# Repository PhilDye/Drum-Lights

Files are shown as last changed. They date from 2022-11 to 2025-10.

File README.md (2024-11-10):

# Drum Lights

## About

This project provides synchronised, colour-changing, remote-control LED lights for a drum band (but could be used for other similar applications). It was first created for [Swan Samba](https://www.swansamba.co.uk) to use for evening/winter performances.

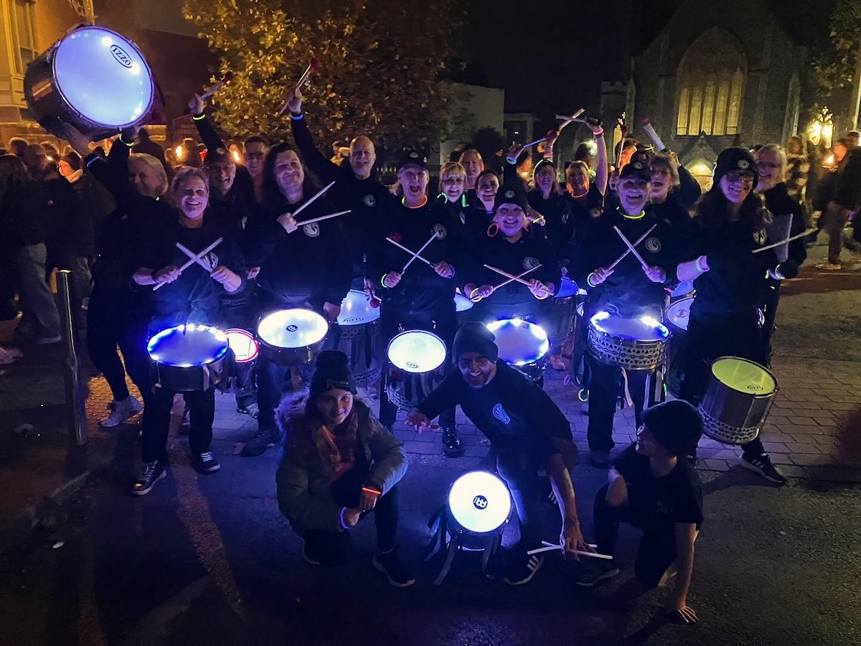
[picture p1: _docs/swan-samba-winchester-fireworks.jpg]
Swan Samba at Winchester Fireworks


Hundreds of hours have gone into developing this project - if you make use of it and wish to thank me, then please consider a donation;



Contributions to improve this documentation or code would also be very welcome to help other users.

## Skills & Requirements

This is a technically complex project! Whilst I've partly documented it here, to use it successfully you'll need to improvise a bit and will need some experience with;

- sourcing and assembling the electronic components (eg from AliExpress), including soldering techniques

- building and uploading the firmware using [Visual Studio Code](https://code.visualstudio.com/) and [PlatformIO](https://platformio.org/)

- 3D-printing for the enclosure boxes

If you are not confident with these skills, then this probably isn't the project for you; I'm happy to answer the odd question, but this project is provided 'as-is' and as a hobby I'm unable to provide extensive support, sorry!

## Overview

The system consists of two components;

- Transmitter (TX) - provides a web-based interface to select required colours/patterns, and broadcasts a radio signal to the receivers.

- Receiver (RX) - receives the broadcast radio signal and drives a strip of individually-addressable LED pixels mounted inside the shell of each drum.

Both are powered by portable USB battery packs ('power banks'), typically carried in a pocket by each band member (or could be mounted to each drum).

## Transmitter

The transmitter (TX) consists of an ESP32 dev-kit board plus a RF24-based radio module, mounted on proto-board.

Although the RF24 modules use the 2.4Ghz ISM radio band, they are not WiFi (which is available on the ESP32 already); this was chosen for low-latency and avoiding the need for a network router for a large number of receivers (which would not be able to connect simultaneously to the ESP32 hotspot).

Significantly better results have been found with the E01-2G4M27D module, rather than the cheaper basic nRF24L01-PA-LNA which suffers RF interference and instability.

The ESP32 also broadcasts a WiFi personal hotspot (configured as a captive portal) to allow a user who wants to control the display to connect simply from their mobile phone.

It runs an AsyncWebServer serving a simple HTML/CSS/JS page from a filesystem, with control commands received by websocket (allowing simultaneous control from multiple clients if required).

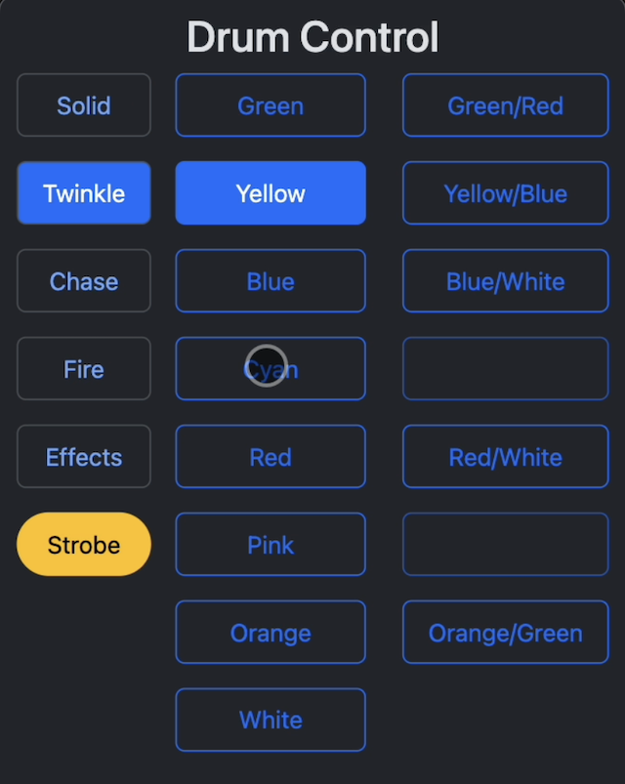
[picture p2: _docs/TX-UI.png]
TX UI


The RF24 module uses a configurable transmit power with multiple channels available, but does not avoid packet collision with other sources using the same frequency. For this reason we retransmit each command multiple times in quick succession, in the hope that 'one gets through'. It also requires a stable 3.3v supply, which at high-power transmission could exceed that available from the ESP32, so a separate buck converter is used fed from the power supply.

## Receiver

The receiver (RX) consists of an ESP8266-based Wemos D1-mini clone board, plus a RF24 module, mounted on a PCB.

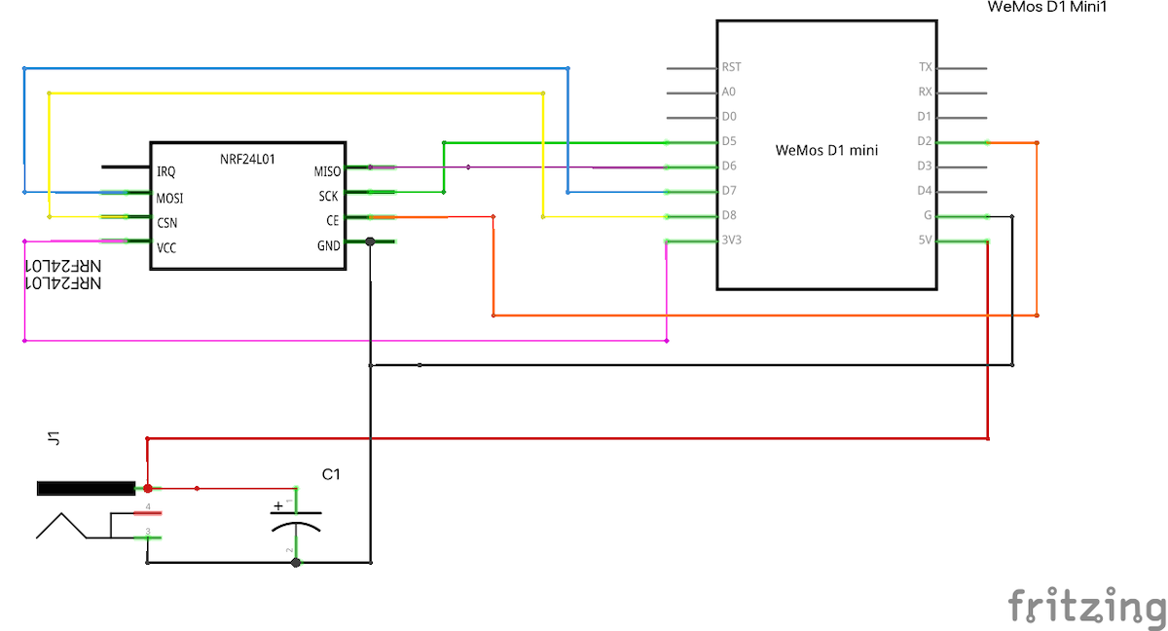
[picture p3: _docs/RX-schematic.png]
RX schematic


Better reliability has been found with the E01-ML01DP4 module, rather than the cheaper basic nRF24L01. 

It receives radio commands from the TX and uses these to drive a strip of WS2812B LEDs ("neopixels") using the excellent [FastLED](https://fastled.io) library.

Best-practice often requires the use of a 3.3v level-shifter and/or resistor in the data line, but testing showed this not to be neccessary, probably given the short data-line length, although a capacitor _is_ provided on the power supply (although as a DC source, USB battery packs are probably sufficiently stable already). 

The receiver reads a configuration file with the number of LEDs available in the attached strip, and uses this to dynamically compute moving effects to suit the varying drum sizes within a band. This file should be uploaded to the filesystem on each board.

## LED mounting

Self-adhesive IP65 WS2812B LED strip is mounted inside the shell of each drum, approx a quarter of the way from the top, around the full circumference. 

The strip requires 3-core cable: 5V, data and ground;
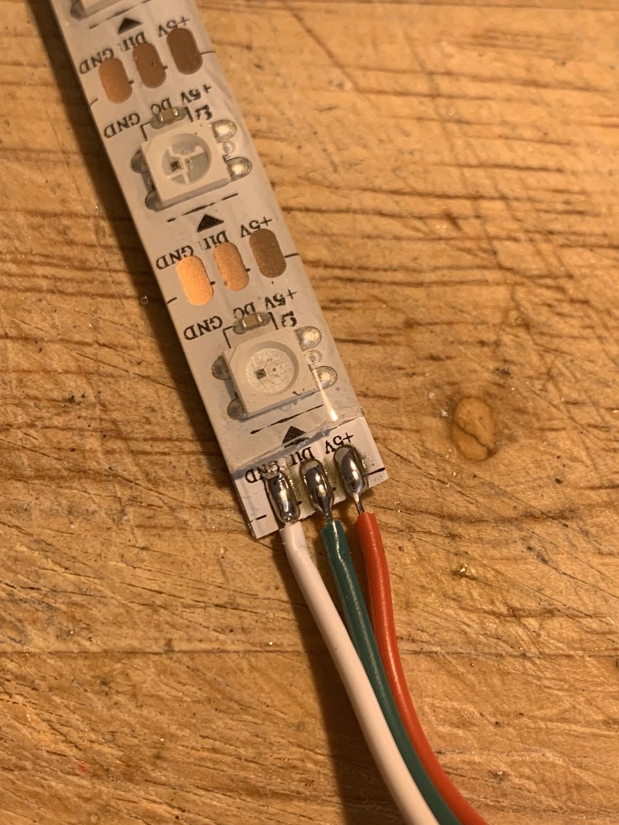
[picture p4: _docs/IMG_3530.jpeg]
WS2812B strip with wires attached


Ensure this is sealed with silicone or hot-glue to prevent water ingress, and insulated with heatshrink;
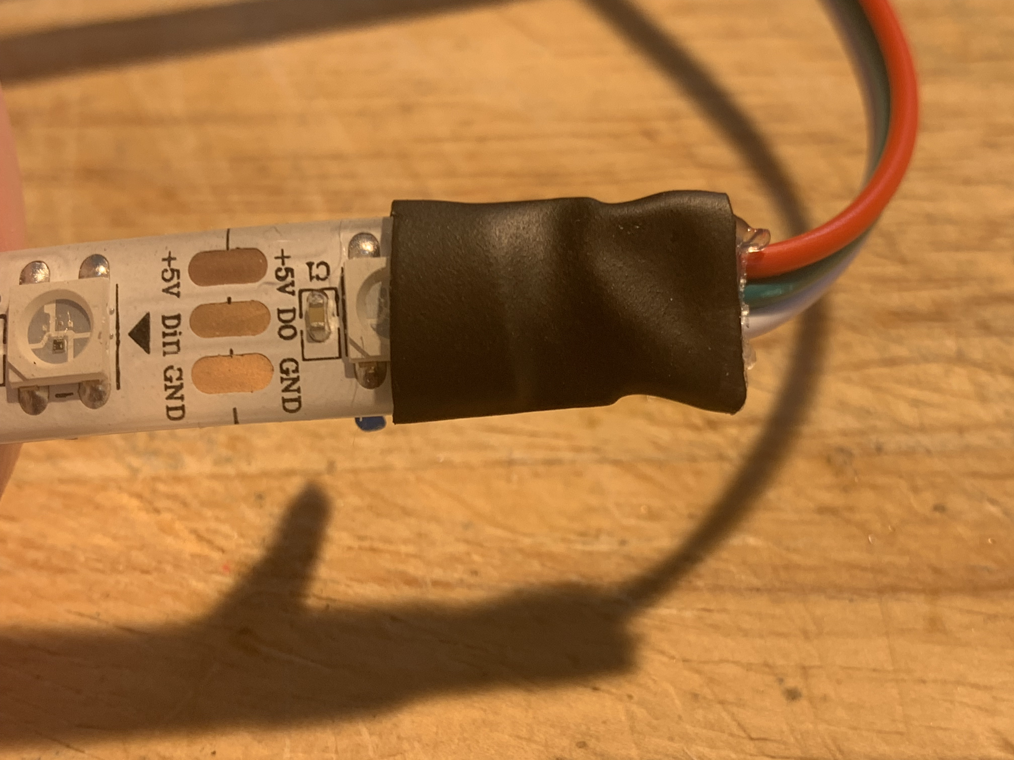
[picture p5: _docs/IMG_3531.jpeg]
WS2812B strip with heatshrink


The cable exits through the sound hole/port and runs to an enclosure holding the RX board.

## Enclosures

Both RX and TX are mounted in custom 3D-printed boxes; the RX in particular is designed to secure the components against vibration. Power is supplied via a 5.5mm DC jack using a [USB cable](https://www.kenable.co.uk/en/usb-cables-adapters/usb-20-cables/usb-20-adapters/7629-usb-to-dc-power-cable-usb-20-for-21mm-x-55mm-5v-2a-2000ma-1m-007629-5055383476299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).

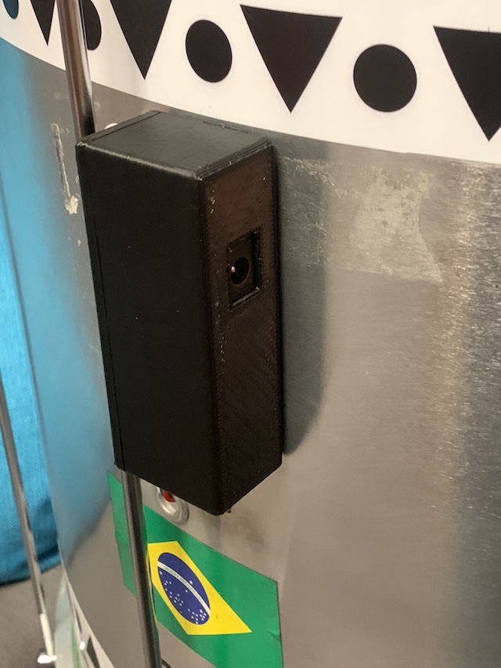
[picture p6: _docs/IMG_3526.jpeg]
3D-printed enclosure mounted on a surdo drum


Experience has shown it's best to mount the RX on the *rear* of all drums with 3M VHB double-sided tape. Ensure the TX is positioned at the rear of the band too, to avoid metal-shelled drums blocking the RF signal. _Ensure players know this to mount their drum accordingly!_

## PCBs

After breadboard prototyping, initial builds were built on protoboard but for more than a small handful of boards (which require plenty of soldering!), it's advisable to consider custom-printed PCBs. 

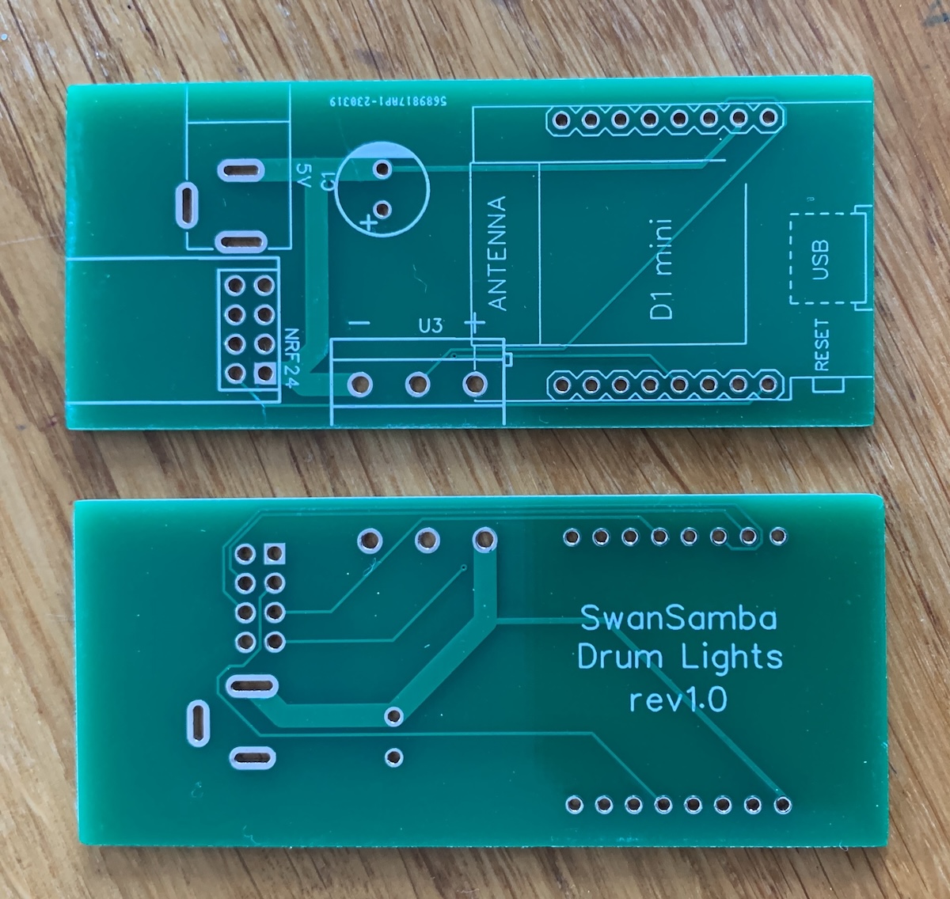
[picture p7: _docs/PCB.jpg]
Custom PCB


[Design files are provided](PCB/) for [KiCAD](https://www.kicad.org/) with Gerber output files ready for use at [JLCPCB](https://jlcpcb.com/).

## Effects

The lighting patterns currently available are;

- Static: every pixel the same colour, available in various colours.
- Chase: 4 quadrants of moving pixels with a fading 'tail', rotating around the drum, available in various colours.
- Twinkle: a number of pixels randomly light then fade, available in various colours.
- Fire: a 'flickering' flame effect in varying colours.
- 'Rio Spin': 3 segments of solid colour (blue/green/yellow) rotating around the drum.
- 'Rio Disco': twinkle, with blue/green/yellow only.
- 'Rio Flag': a blue/green/yellow sequence representing the Brazilian flag, rotating around the drum.
- Rainbow: a classic FastLED multi-colour effect, rotating around the drum.
- Hazards: 2 segments of orange at the side of each drum, designed to imitate a vehicle's hazard lights when stopped.
- Strobe: rapid, short-duration flashes of full-intensity white - perfect for big hits!
- 999: alternate high-frequency flashing blue strobes (named after the UK emergency-services telephone number).
- Auto: randomises most of the above every 30s; ideal to 'fire-and-forget' if no-one is available to run the show.

Many of the FastLED demo effects suit 1D (strip) or 2D (panel) setups; the circular/ring configuration here does present some additional challenges, but further effects are really only limited by imagination (although compexity of the control UI should be considered).

## Synchronicity

Currently, all drums receive the same command and hence display the same colour/pattern at the same time. The speed of the rotating patterns (ie RPM) is not synchronised across varying diameter drums; early experiments showed this to be hard to maintain a smooth frame rate at slower speeds (on smaller drums); temporal dithering may help this.

It would be relatively simple to use addressing or channel features of the RF24 to control each drum type seperately, allowing complex displays and patterns 'across' the band. The main obstacle is likely to be the complexity of the control UI.

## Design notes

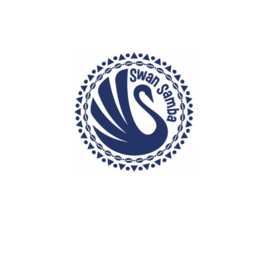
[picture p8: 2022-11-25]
TX/app/src/public/mstile-150x150.png

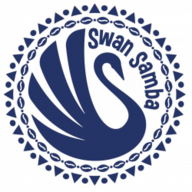
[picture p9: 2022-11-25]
TX/app/src/public/android-chrome-192x192.png

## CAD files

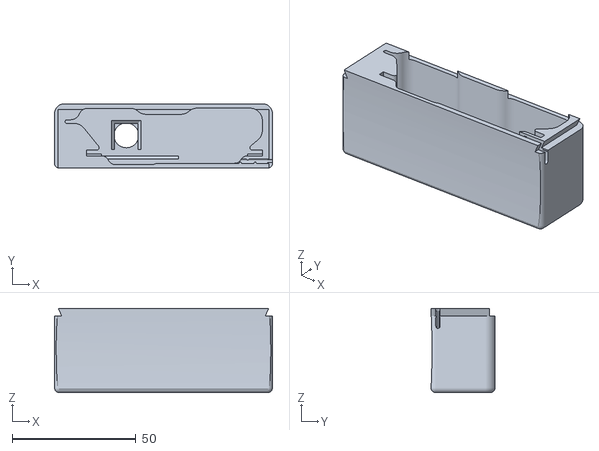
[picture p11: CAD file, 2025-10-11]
STL/box.stl
88.0 x 26.0 x 34.0

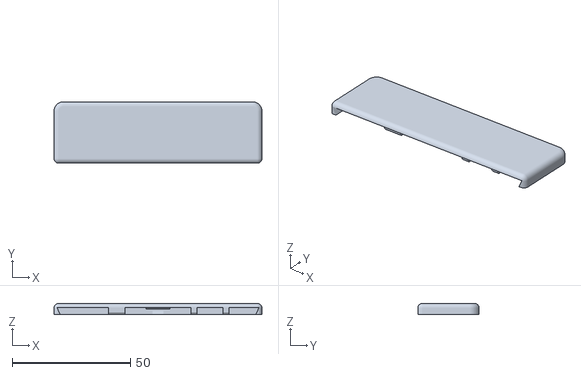
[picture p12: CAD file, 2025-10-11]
STL/lid.stl
88.0 x 26.0 x 4.75

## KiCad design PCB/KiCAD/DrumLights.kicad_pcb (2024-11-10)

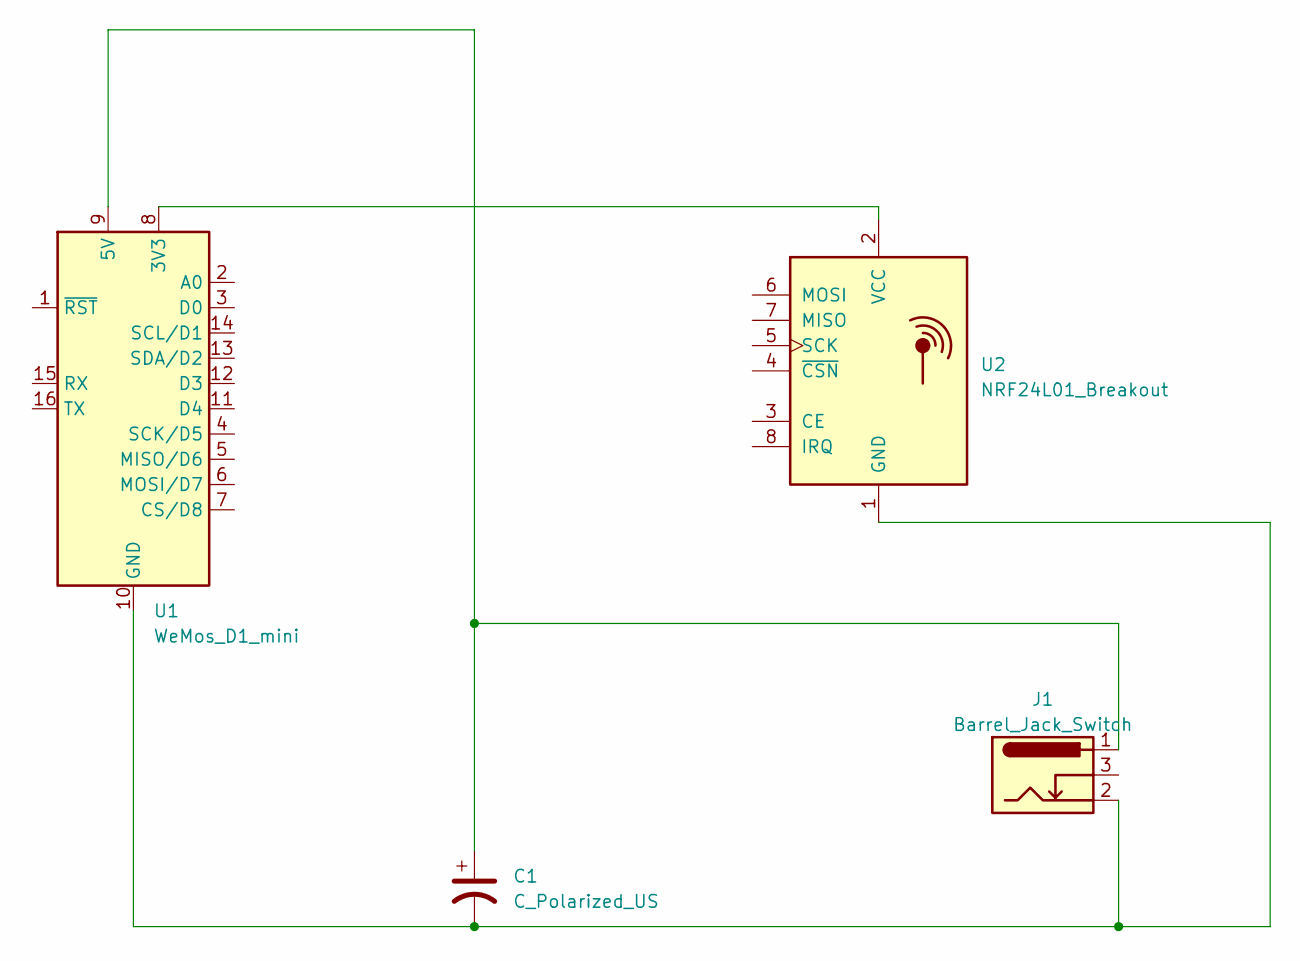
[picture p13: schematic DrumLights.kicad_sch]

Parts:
C1: C_Polarized_US; CP_Radial_D6.3mm_P2.50mm
J1: Barrel_Jack_Switch; BarrelJack_Horizontal
U1: WeMos_D1_mini; WEMOS_D1_mini_light
U2: NRF24L01_Breakout; nRF24L01_Breakout

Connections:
unnamed: U1.8 (3V3), U2.2 (VCC)
unnamed: C1.1, J1.1, U1.9 (5V)
unnamed: C1.2, J1.2, U1.10 (GND), U2.1 (GND)

Board: 2 copper layers, 4 parts (0 on the bottom side), 3 nets, no tracks yet.

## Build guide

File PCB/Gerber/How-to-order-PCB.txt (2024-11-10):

How to Order PCB

Please refer to:
https://docs.easyeda.com/en/PCB/Order-PCB

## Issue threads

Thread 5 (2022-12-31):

Continual re-broadcasting current mode

PhilDye, 2022-12-31:
To allow for drums rebooting (eg from power issues or joining late), need to periodically re-transmit the current mode. Need to consider power usage, and not 'restarting' any current animation (eg jumping the rotation position)

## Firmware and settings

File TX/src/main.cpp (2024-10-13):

/* Drum Lights transmitter
 *
 * by Phil Dye <phil@phildye.org>
 * for Swan Samba Band <https://www.swansamba.co.uk>
 *
 * Works with the Drum Lights Receiver
 * to send desired colour/pattern commands from a web UI
 * by nRF24L01 radio module
 *
 */

#include <WiFi.h>
#include <AsyncTCP.h>
#include <ESPAsyncWebServer.h>
#include <DNSServer.h>
#include <esp_wifi.h> //Used for mpdu_rx_disable android workaround
#include <SPI.h>
#include <nRF24L01.h>
#include <RF24.h>
#include <LittleFS.h>
#include <ArduinoJson.h>
#include <millisDelay.h>

#include <secrets.h>

// Setup the network
const byte DNS_PORT = 53;
const byte HTTP_PORT = 80;
const IPAddress localIP(192, 168, 4, 1);          // the IP address the web server, Samsung requires the IP to be in public space
const IPAddress gatewayIP(192, 168, 4, 1);        // IP address of the network should be the same as the local IP for captive portals
const IPAddress subnetMask(255, 255, 255, 0); // no need to change: https://avinetworks.com/glossary/subnet-mask/
const String localIPURL = "http://192.168.4.1";   // a string version of the local IP with http, used for redirecting clients to your webpage
#define DNS_INTERVAL 30

// Setup the servers
AsyncWebServer webServer(HTTP_PORT);
AsyncWebSocket ws("/ws");
DNSServer dnsServer;

// Setup the nRF24L01 radio
#define NRF24L01_PIN_CE 17
#define NRF24L01_PIN_CS 5
RF24 radio(NRF24L01_PIN_CE, NRF24L01_PIN_CS);
const byte address[5] = {'R', 'x', 'A', 'A', '1'};
const byte RETRANSMITS = 5; // how many times we retransmit every message, for reliability in noisy RF environments

#define LED_BUILTIN 2

int CurrentMode = 0;

const unsigned long AUTO_TIME = 30000; // in mS
const int AUTO_MODE = -1;
millisDelay autoDelay; // the delay object

const int autoModes[24] = {
    1, 2, 3, 4, 5, 6, 7, 8,
    11, 12, 13, 14, 15, 16, 17, 18,
    81, 82, 83, 84, 85, 86, 87, 88};

class CaptiveRequestHandler : public AsyncWebHandler
{
public:
    explicit CaptiveRequestHandler(String redirectTargetURL) :
        targetURL("http://" + WiFi.softAPIP().toString() + redirectTargetURL)
    {
    }
    virtual ~CaptiveRequestHandler() {}

    const String targetURL;

    bool canHandle(AsyncWebServerRequest *request) override
    {
        // redirect if not in wifi client mode (through filter)
        // and request for different host (due to DNS * response)
        if (request->host() != WiFi.softAPIP().toString())
            return true;
        else
            return false;
    }

    void handleRequest(AsyncWebServerRequest *request) override
    {
        request->redirect(targetURL);
        log_d("Captive handler triggered. Requested %s%s -> redirecting to %s", request->host().c_str(), request->url().c_str(), targetURL.c_str());
    }
};

void initRadio()
{
  // initialize the transceiver on the SPI bus
  if (!radio.begin())
  {
    Serial.println(F("Radio hardware is not responding!!"));
    // hold in infinite loop
    while (1)
      digitalWrite(LED_BUILTIN, millis() % 1000 < 500 ? HIGH : LOW);
  }

  radio.openWritingPipe(address);
  // Set the PA Level to try preventing power supply related problems
  radio.setPALevel(RF24_PA_MAX); // RF24_PA_MAX is default
  radio.setAutoAck(false);
  radio.stopListening(); // put radio in TX mode

  radio.printPrettyDetails(); // (larger) function that prints human readable data
}

void setUpWebserver(AsyncWebServer &webServer, const IPAddress &localIP)
{
  	// Required
	webServer.on("/connecttest.txt", [](AsyncWebServerRequest *request) { request->redirect("http://logout.net"); });	// windows 11 captive portal workaround
	webServer.on("/wpad.dat", [](AsyncWebServerRequest *request) { request->send(404); });								// Honestly don't understand what this is but a 404 stops win 10 keep calling this repeatedly and panicking the esp32 :)

	// Background responses: Probably not all are Required, but some are. Others might speed things up?
	// A Tier (commonly used by modern systems)
	webServer.on("/generate_204", [](AsyncWebServerRequest *request) { request->redirect(localIPURL); });		   // android captive portal redirect
	webServer.on("/redirect", [](AsyncWebServerRequest *request) { request->redirect(localIPURL); });			   // microsoft redirect
	webServer.on("/hotspot-detect.html", [](AsyncWebServerRequest *request) { request->redirect(localIPURL); });  // apple call home
	webServer.on("/canonical.html", [](AsyncWebServerRequest *request) { request->redirect(localIPURL); });	   // firefox captive portal call home
	webServer.on("/success.txt", [](AsyncWebServerRequest *request) { request->send(200); });					   // firefox captive portal call home
	webServer.on("/ncsi.txt", [](AsyncWebServerRequest *request) { request->redirect(localIPURL); });			   // windows call home
  
  webServer.addHandler(new CaptiveRequestHandler("/")).setFilter(ON_AP_FILTER); // only when requested from AP
  webServer.serveStatic("/", LittleFS, "/").setDefaultFile("index.html").setCacheControl("max-age=600");;
  webServer.onNotFound([](AsyncWebServerRequest *request) { request->redirect(localIPURL); });

  webServer.begin();
}

void notifyClients()
{
  const size_t size = JSON_OBJECT_SIZE(1);
  StaticJsonDocument<size> json;
  json["mode"] = CurrentMode;

  char msg[32];
  size_t len = serializeJson(json, msg);
  ws.textAll(msg, len);

  Serial.printf("CurrentMode #%d broadcasted to WS\n", CurrentMode);
}

void broadcastRF()
{
  for (size_t i = 0; i < RETRANSMITS; i++)
  {
    radio.write(&CurrentMode, sizeof(CurrentMode), true);
    delay(10);
  }
  Serial.printf("CurrentMode #%d broadcasted to RF\n", CurrentMode);
}

void handleWSMessage(void *arg, uint8_t *data, size_t len)
{
  AwsFrameInfo *info = (AwsFrameInfo *)arg;
  if (info->final && info->index == 0 && info->len == len && info->opcode == WS_TEXT)
  {

    const size_t size = JSON_OBJECT_SIZE(1);
    StaticJsonDocument<size> json;
    DeserializationError err = deserializeJson(json, data);
    if (err)
    {
      Serial.print(F("deserializeJson() failed with code "));
      Serial.println(err.c_str());
      return;
    }

    int previousMode = CurrentMode;

    int newMode = json["mode"];

    Serial.printf("Received mode #%d\n", newMode);

    if (newMode == AUTO_MODE)
    { // auto
      Serial.printf("AUTO mode set ON\n");

      // set a random mode
      newMode = autoModes[random(24)];
      Serial.printf("CurrentMode randomised to #%d\n", newMode);
      autoDelay.start(AUTO_TIME);
    }
    else if (CurrentMode = AUTO_MODE)
    {
      autoDelay.stop();
      Serial.printf("AUTO mode set OFF\n");
    }

    CurrentMode = newMode;
    Serial.printf("CurrentMode set to #%d\n", CurrentMode);

    broadcastRF();

    if (newMode == 98)
    { // revert mode for strobe (RX automatically revert so no need to TX)
      CurrentMode = previousMode;
      Serial.printf("CurrentMode reverted to #%d\n", previousMode);
    }

    notifyClients();
  }
}

void onWSEvent(AsyncWebSocket *server,
             AsyncWebSocketClient *client,
             AwsEventType type,
             void *arg,
             uint8_t *data,
             size_t len)
{

  switch (type)
  {
  case WS_EVT_CONNECT:
    Serial.printf("WebSocket client #%u connected from %s\n", client->id(), client->remoteIP().toString().c_str());
    break;
  case WS_EVT_DISCONNECT:
    Serial.printf("WebSocket client #%u disconnected\n", client->id());
    break;
  case WS_EVT_DATA:
    Serial.printf("WebSocket data received\n");
    handleWSMessage(arg, data, len);
    break;
  case WS_EVT_PONG:
  case WS_EVT_ERROR:
    break;
  }
}

void initWebSocket()
{
  ws.onEvent(onWSEvent);
  webServer.addHandler(&ws);
}

void setUpDNSServer(DNSServer &dnsServer, const IPAddress &localIP)
{
  // Respond to all DNS requests with the ESP's IP
  dnsServer.setErrorReplyCode(DNSReplyCode::NoError);
  dnsServer.setTTL(3600);
  dnsServer.start(DNS_PORT, "*", WiFi.softAPIP());
  Serial.println("DNS server started");
}

void startAccessPoint(const char *ssid, const char *password, const IPAddress &localIP, const IPAddress &gatewayIP, const IPAddress &subnetMask)
{
#define WIFI_CHANNEL 6

  // Set the WiFi mode to access point and station
  WiFi.mode(WIFI_MODE_AP);

  // Configure the soft access point with a specific IP and subnet mask
  WiFi.softAPConfig(localIP, gatewayIP, subnetMask);

  // Start the soft access point with the given ssid, password, channel, max number of clients
  WiFi.softAP(ssid, password, WIFI_CHANNEL);

  // Disable AMPDU RX on the ESP32 WiFi to fix a bug on Android
  esp_wifi_stop();
  esp_wifi_deinit();
  wifi_init_config_t my_config = WIFI_INIT_CONFIG_DEFAULT();
  my_config.ampdu_rx_enable = false;
  esp_wifi_init(&my_config);
  esp_wifi_start();
  vTaskDelay(100 / portTICK_PERIOD_MS); // Add a small delay
}

void setup()
{
  pinMode(LED_BUILTIN, OUTPUT);

  Serial.begin(115200);
  while (!Serial)
  {
    // some boards need to wait to ensure access to serial over USB
  }

  initRadio();

  if(!LittleFS.begin(true)){
    Serial.println("An Error has occurred while mounting LITTLEFS");
    return;
  }

  startAccessPoint(WIFI_SSID, WIFI_PASS, localIP, gatewayIP, subnetMask);

  setUpDNSServer(dnsServer, localIP);

  setUpWebserver(webServer, localIP);
  webServer.begin();

  initWebSocket();

  Serial.println("Ready; HTTP server started on " + WiFi.softAPIP().toString());
}

void loop()
{
  dnsServer.processNextRequest();
  ws.cleanupClients();

  if (autoDelay.justFinished())
  {
    // set a random mode
    CurrentMode = autoModes[random(24)];
    Serial.printf("CurrentMode randomised to #%d\n", CurrentMode);

    broadcastRF();
    notifyClients();

    autoDelay.repeat(); // repeat
    Serial.println("autoDelay restarted");
  }

  delay(DNS_INTERVAL);  // seems to help with stability, if you are doing other things in the loop this may not be needed
}

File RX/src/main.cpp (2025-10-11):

/* Drum Lights receiver
 *
 * by Phil Dye <phil@phildye.org>
 * for Swan Samba Band <https://www.swansamba.co.uk>
 *
 * Works with the Drum Lights Transmitter
 * to receive desired colour/pattern commands from a web UI
 * by nRF24L01 radio module, and outputs to a WS2812B LED strip
 *
 */

#include <Arduino.h>
#include <SPI.h>
#include <nRF24L01.h>
#include <RF24.h>
#define FASTLED_ALLOW_INTERRUPTS 0
#include <FastLED.h>
#include "FS.h"
#include <SPIFFSIniFile.h>

#include "prototypes.h"

#if FASTLED_VERSION < 3001000
#error "Requires FastLED 3.1 or later; check github for latest code."
#endif

// Setup the nRF24L01 radio
#define NRF24L01_PIN_CE 4
#define NRF24L01_PIN_CS 15
struct RF24 radio(NRF24L01_PIN_CE, NRF24L01_PIN_CS);
const byte address[5] = {'R', 'x', 'A', 'A', '1'};

// Setup the LEDs
#define MAX_LEDS 104 // Maximum number of LEDS to initialise for
#define DATA_PIN 2
#define VOLTS 5
#define MAX_MA 2000
#define FRAMES_PER_SECOND 35
byte max_bright = 255;      // Overall brightness definition, could be changed on the fly
struct CRGB leds[MAX_LEDS]; // The array of leds, one for each led in the strip
int numLeds = MAX_LEDS;     // To be read from config later

int ledMode = -1;                  // The currently active pattern
unsigned long IDLETIMEOUT = 30000; // Time to wait before doing our own thing

void (*resetFunc)(void) = 0; // declare reset function @ address 0

void showStatus(struct CRGB *targetArray, const struct CRGB &color)
{
  EVERY_N_MILLIS(1000)
  {
    targetArray[1] = color;
    FastLED.show();
    FastLED.delay(500);
    FastLED.clear(true);
    FastLED.delay(500);
  }
}

void showError(struct CRGB *targetArray, const struct CRGB &color)
{
  EVERY_N_MILLIS(300)
  {
    targetArray[1] = color;
    FastLED.show();
    FastLED.delay(150);
    FastLED.clear(true);
    FastLED.delay(150);
  }
}

void setup()
{
  Serial.begin(115200);
  while (!Serial)
  {
    // some boards need to wait to ensure access to serial over USB
  }
  delay(1000);

  Serial.println("Setting up...");

#pragma region CONFIGFILE

  // to read config file
  const byte bufferLen = 80;
  char buffer[bufferLen];

  const char *filename = "/config.ini";

  // Mount the SPIFFS
  if (!SPIFFS.begin())
  {
    Serial.println("SPIFFS.begin() failed");
    ledMode = -2;
  }

  SPIFFSIniFile ini(filename);
  if (!ini.open())
  {
    Serial.print("ini file ");
    Serial.print(filename);
    Serial.println(" does not exist");
    ledMode = -2;
  }

  // Check the file is valid. This can be used to warn if any lines
  // are longer than the buffer.
  if (!ini.validate(buffer, bufferLen))
  {
    Serial.print("ini file ");
    Serial.print(ini.getFilename());
    Serial.print(" not valid: ");
    ledMode = -2;
  }

#pragma endregion CONFIGFILE

  if (ini.getValue("leds", "count", buffer, bufferLen, numLeds))
  {
    Serial.print("Got numLeds from config: ");
    Serial.println(numLeds);
  }
  int drumType = 0;
  if (ini.getValue("drum", "type", buffer, bufferLen, drumType))
  {
    Serial.print("Got drum type from config: ");
    Serial.println(drumType);
  }
  ini.close();

  Serial.print("Setting up LEDs... ");
  FastLED.addLeds<WS2812, DATA_PIN, GRB>(leds, numLeds).setCorrection(TypicalPixelString);
  
  FastLED.setBrightness(max_bright);
  FastLED.setMaxPowerInVoltsAndMilliamps(VOLTS, MAX_MA);
  FastLED.clear();
  Serial.println("Done");

  Serial.printf("ESP8266 Chip id = %08X\n", ESP.getChipId());

  Serial.print("Setting up radio... ");
  if (radio.begin())
  {
    radio.openReadingPipe(1, address);
    radio.setAutoAck(false);
    radio.startListening();     // put radio in TX mode
    radio.printPrettyDetails(); // (larger) function that prints human readable data
    Serial.print("done");

    ledMode = -1;
  }
  else
  {
    Serial.println(F("radio hardware is not responding!!"));
    ledMode = -3;
    showError(leds, CRGB::Red);
  }
}

void readRadio()
{
  byte pipe;

  if (radio.available(&pipe))
  { // is there a payload?
    int payload;
    radio.read(&payload, sizeof(payload)); // get incoming payload
    ledMode = payload;

    Serial.print("Radio RX data: ");
    Serial.println(ledMode);

    // clear all pixels ready for the new mode
    FastLED.clear();
  }
}

void loop()
{
  // Add entropy to random number generator; we use a lot of it
  random16_add_entropy(random());

  if (ledMode < 0 && millis() > IDLETIMEOUT) // no mode set yet
  {
    ledMode = 63; // swan samba twinkle
  }

  int currentMode = ledMode;

  readRadio();

  switch (ledMode)
  {
  case -1:
  case 0:
    showStatus(leds, CRGB::DarkGreen);
    break;

  case 1:
    fill_solid(leds, numLeds, CRGB::Green);
    break;
  case 2:
    fill_solid(leds, numLeds, CRGB::Gold);
    break;
  case 3:
    fill_solid(leds, numLeds, CRGB::Blue);
    break;
  case 4:
    fill_solid(leds, numLeds, CRGB::Red);
    break;
  case 5:
    fill_solid(leds, numLeds, CRGB::White);
    break;
  case 6:
    fill_solid(leds, numLeds, CRGB::Cyan);
    break;
  case 7:
    fill_solid(leds, numLeds, CRGB::Indigo);
    break;
  case 8:
    fill_solid(leds, numLeds, CRGB::OrangeRed);
    break;

  case 21:
    chase(leds, numLeds, CRGB::Green, CRGB::Red); // Christmas
    break;
  case 22:
    chase(leds, numLeds, CRGB::Gold, CRGB::Blue); // Ukraine
    break;
  case 23:
    chase(leds, numLeds, CRGB::Blue, CRGB::White); // Swan Samba
    break;
  case 24:
    chase(leds, numLeds, CRGB::Red, CRGB::White); // Red-White
    break;
  case 28:
    chase(leds, numLeds, CRGB::OrangeRed, CRGB::Green); // Halloween
    break;

  case 11:
    chase(leds, numLeds, CRGB::Green);
    break;
  case 12:
    chase(leds, numLeds, CRGB::Gold);
    break;
  case 13:
    chase(leds, numLeds, CRGB::Blue);
    break;
  case 14:
    chase(leds, numLeds, CRGB::Red);
    break;
  case 15:
    chase(leds, numLeds, CRGB::White);
    break;
  case 16:
    chase(leds, numLeds, CRGB::Cyan);
    break;
  case 17:
    chase(leds, numLeds, CRGB::Indigo);
    break;
  case 18:
    chase(leds, numLeds, CRGB::OrangeRed);
    break;

  case 50:
    fire(leds, numLeds, WoodFireColors_p);
    break;
  case 51:
    fire(leds, numLeds, CopperFireColors_p);
    break;
  case 52:
    fire(leds, numLeds, AlcoholFireColors_p);
    break;
  case 53:
    fire(leds, numLeds, LithiumFireColors_p);
    break;

  // bi-colors
  case 61:
    colorTwinkle(leds, numLeds, CRGB::Green, CRGB::Red);
    break;
  case 62:
    colorTwinkle(leds, numLeds, CRGB::Gold, CRGB::Blue);
    break;
  case 63:
    colorTwinkle(leds, numLeds, CRGB::Blue, CRGB::White);
    break;
  case 64:
    colorTwinkle(leds, numLeds, CRGB::Red, CRGB::White);
    break;
  case 68:
    colorTwinkle(leds, numLeds, CRGB::OrangeRed, CRGB::Green);
    break;
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

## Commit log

2022-10-08 Combine RX and TX repos
    [Drum Lights.fzz]
2022-11-06 Filesystem for config and web UI (#1)
    * WIP
    * Switch to match hardware
    * Show better error on radio error
    * Radio changes to support multiple RXs
    * Strobe mode!
    * Size for largest drum
    * change address
    * Send TX three times for reliability
    * Support for strobe
    * Support for toggle off
    * Fix strobe crashing in twinkle
    * Add hazards
    * Config file for number of LEDs
    * Use a constant for retransmits
    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
    [main.cpp]
2022-11-26 Off button instead of toggle to allow re-sending
2024-09-17 feat: improve status and add orange
    commit 50e533feae007a89972b5c5836e0d8f8052f43fb
    Author: Phil Dye <phil@phildye.org>
    Date: Tue Sep 17 20:58:13 2024 +0100
    feat: add orange
    commit 84422e6047ac221cc4507d9b890e7efa47c629d0
    Author: Phil Dye <phil@phildye.org>
    Date: Tue Sep 17 20:57:47 2024 +0100
    feat: improve pink
    commit 629da68dd319bb49e9f5a3aafabfd7bff73f91dd
    Author: Phil Dye <phil@phildye.org>
    Date: Tue Sep 17 20:57:17 2024 +0100
    feat: improve blue
    commit 2c491d9128694196a07df67d0593255d02709439
    Author: Phil Dye <phil@phildye.org>
    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
    [main.cpp]
2024-09-17 feat: default to blue chase after power-on idle
    allows drums to operate without the TX
2024-09-22 fix: random auto initialiser
    [main.cpp]
2024-09-25 feat: SaintsFC 😂
2024-09-25 chore: use correct board
2024-10-13 feat: replace deprecated spiffs with littlefs
    [main.cpp]
2024-10-13 feat: use stronger button for strobe
2024-10-13 fix: close ini file
    [main.cpp]
2024-10-13 fix: major 🐛 with reading payload
    Not quite sure what was happening here, but reading unsigned `int` straight into signed `ledMode`?
    [main.cpp]
2024-10-13 fix: red fire wasn't red
    [main.cpp]
2024-11-10 docs: improved, with pics
    [DrumLights.kicad_pcb, DrumLights.kicad_sch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]
2025-10-11 feat: add 3d print files
    [box.stl, lid.stl]
2026-10-25 fix(TX): sync new WS clients and surface Auto state (#16)
    * fix(TX): sync new WS clients and surface Auto state
    Factor state serialization into buildStateMessage() that emits both
    mode and auto (= autoDelay.isRunning()), and send it to each client
    on WS_EVT_CONNECT so late joiners see what the drums are doing
    without waiting for a mode change (#13).
    Include the auto flag in every broadcast and highlight #btnAuto in
    the web UI when it is true, so Auto no longer looks like a random
    manual pick (#14).
    Also replace the buggy `else if (CurrentMode = AUTO_MODE)` assignment
    with an `autoDelay.isRunning()` check — functionally close to the
    previous behaviour but no longer clobbering CurrentMode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
2026-10-25 refactor(TX): route every mode change through applyMode() (#25)
    handleWSMessage() and the Auto timer in loop() each had their own copy
    of the mode logic. Now:
    - applyMode(mode): single entry point for a requested mode (Auto on,
    one-shot Strobe that leaves Auto and CurrentMode alone, anything
    else stops Auto)
    - sendMode(mode): set CurrentMode, broadcast over RF, notify clients
    - nextAutoMode(): the Auto timer's step
    - notifyAll(): renamed from notifyClients(), the hook for BLE later
    - broadcastRF(mode) takes the mode, so Strobe no longer has to set and
    restore CurrentMode around the broadcast
    No behaviour change intended. Part of #18.
    Claude-Session: https://claude.ai/code/session_0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
2026-10-25 refactor(TX): queue mode requests and apply them on the loop task (#26)
    handleWSMessage() now only parses the JSON and enqueues the mode with
    requestMode() into a small FreeRTOS queue. loop() drains the queue and
    calls applyMode(), so mode state, the Auto timer, radio writes and
    notifications all happen on the Arduino loop task. This stops each
    WebSocket command blocking the AsyncTCP task for ~50 ms of RF
    retransmits and removes the unlocked cross-task access to CurrentMode,
    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
2026-10-25 chore: pin SDK to avoid ipv6 issues
2026-10-25 ci: add GitHub Actions workflow to build TX firmware (#29)
    * ci: add GitHub Actions workflow to build TX firmware
    Runs `pio run` in TX/ on pushes to main, PRs touching TX/**, and
    manual dispatch. Caches PlatformIO packages/platforms and checks out
    full history so version.py's `git describe --tags` resolves.
    * ci: stub TX/src/secrets.h before build
    secrets.h is not tracked, so CI needs to materialise one with dummy
    values for `pio run` to compile.
    ---------
2026-10-25 feat(TX): add modes.json catalogue and render the web UI from it (#30)
    TX/app/src/modes.json is now the single list of modes for the UIs:
    colours (with the FastLED colour and hex the RX uses), effects in
    display order with their single and two-colour modes, named effects,
    the 999 confirm wording, the Strobe/Off/Auto actions and the Auto list.
    The iOS app will bundle the same file.
    Web UI:
    - tabs and buttons are generated from the catalogue; two-colour modes
    sit beside the single colour they start with, as before
    - Strobe, Off and Auto keep their places and take their numbers from it
    - the 999 confirm modal is driven by the entry's confirm text
    - fixes the Strobe button closing with </a>
    -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
2026-10-25 docs: drop keyboard and pedal control from the iOS design (#40)
    There is no keyboard control expected anywhere: remove keys 1 to 9 /
    Space and Bluetooth pedals from the app, the web UI plan, the phase 3
    scope and the rehearsal check, and the tile slot numbers that only
    existed for them. The mockup README notes the leftover numbers.
    Claude-Session: https://claude.ai/code/session_01Jj8bW7pBTpudvXFsJW2YVr
2026-11-02 feat(TX): BLE GATT service on an ESP32-S3 for the iOS app (#20) (#44)
    * feat(TX): BLE GATT service on an ESP32-S3 for the iOS app (#20)
    The TX moves to an ESP32-S3 (new default env `esp32-s3`), because the
    classic ESP32's BLE controller connected 8/10 at 4.4 s against 20/20 at
    1.0 s on an S3 (#19). The classic env stays, web UI only, so existing
    transmitters and the current PCB still build and get fixes.
    BLE (NimBLE-Arduino, S3 only):
    - Service 9A9476F2-...: State (read, notify; int32 mode + flags bit 0 =
    auto), Command (write with response, encrypted and authenticated;
    int32 mode, -1 = auto), Info (read; proto/fw/catalogue JSON)
    - Bonded LE Secure Connections with a static passkey fro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
2026-11-02 feat(iOS): DrumLightsKit and the Live tab app (#20) (#45)
    - Bonded LE Secure Connections with a static passkey from secrets.h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
2026-11-02 feat: update TX box for ESP32-S3
2026-11-07 Revert "iOS: switch off the Hotspot capability for free accounts"
    This reverts commit 9614cbdd0447410b5139fbf1cb02266372351f9a.
2026-11-09 docs: update root README for the ESP32-S3 TX, iOS app and web UI fallback (#50)
    * docs: update root README for the ESP32-S3 TX, iOS app and web UI fallback
    Claude-Session: https://claude.ai/code/session_018GcAsgbKVpwPKJPrfcekNE
    * docs: add iOS app screenshots from the design mockup to the README
    Claude-Session: https://claude.ai/code/session_018GcAsgbKVpwPKJPrfcekNE
    * docs: keep only the Live tab screenshot in the README
    Claude-Session: https://claude.ai/code/session_018GcAsgbKVpwPKJPrfcekNE
    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
